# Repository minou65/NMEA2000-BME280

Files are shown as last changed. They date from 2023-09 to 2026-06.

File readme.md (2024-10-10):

# NMEA2000-BM280 environmental sensor

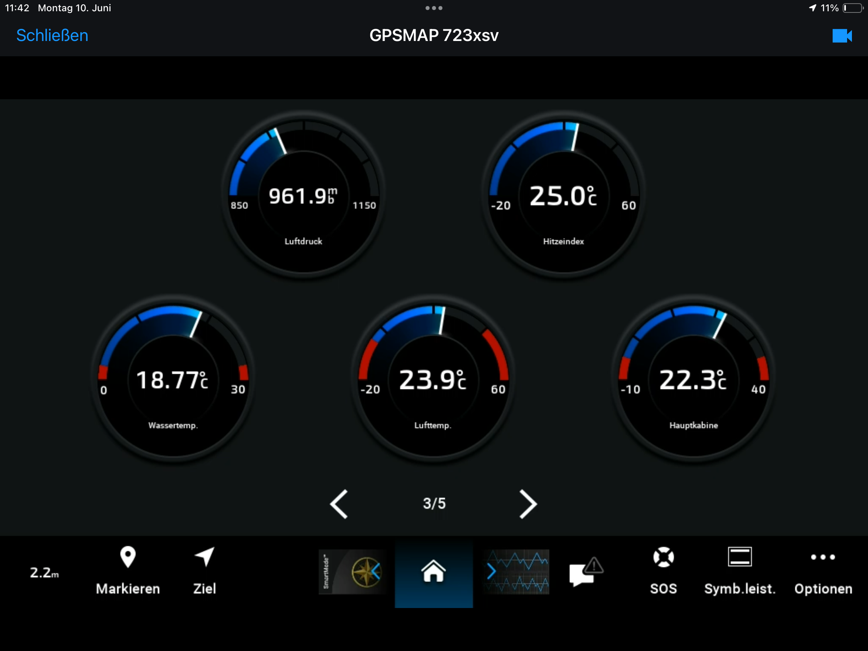
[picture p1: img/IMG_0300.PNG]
garmin


## Table of contents
- [NMEA2000-BM280 environmental sensor](#nmea2000-bm280-environmental-sensor)
  - [Table of contents](#table-of-contents)
  - [Description](#description)
  - [Schema](#schema)
  - [NMEA 2000](#nmea-2000)
  - [Librarys](#librarys)
  - [Part list](#part-list)
  - [Configuration](#configuration)
    - [System Configuration](#system-configuration)
      - [Thing name](#thing-name)
      - [AP password](#ap-password)
      - [WiFi SSID](#wifi-ssid)
      - [WiFi password](#wifi-password)
      - [AP offline mode after (minutes)](#ap-offline-mode-after-minutes)
    - [NMEA configuration](#nmea-configuration)
      - [Instance](#instance)
      - [SID](#sid)
    - [Temperatur source](#temperatur-source)
    - [Humidity source](#humidity-source)
  - [Username and password](#username-and-password)
  - [Default IP address](#default-ip-address)
  - [Firmware Update](#firmware-update)
  - [Blinking codes](#blinking-codes)
  - [Reset](#reset)

## Description
This device measures temperature, humidity, and air pressure. The dew point and perceived temperature are also calculated. The sensor used is a BM280. The values are transmitted as NMEA 2000 messages via an NMEA bus. Device configuration is done through a website, and real-time values can also be viewed on a website in addition to the NMEA bus. On the configuration page, there is a link available for convenient firmware updates.

the BME280 is a versatile environmental sensor that provides accurate measurements of temperature, humidity, and barometric pressure.
- Temperatures ranging from -40°C to +85°C with a high degree of accuracy
- relative humidity in the range of 0% to 100%
- pressure sensor data is in hPa (hectopascals) within the range of 300 hPa to 1100 hPa at temperatures from 0°C to 65°C. The absolute accuracy for pressure measurement is approximately ±1 hPa
  
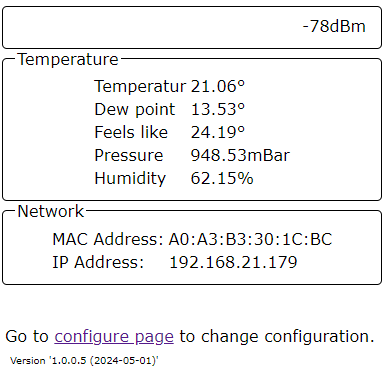
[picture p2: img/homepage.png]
homepage


In the \stl directory are two STL files. These can be used to print an appropriate housing on a 3D printer.

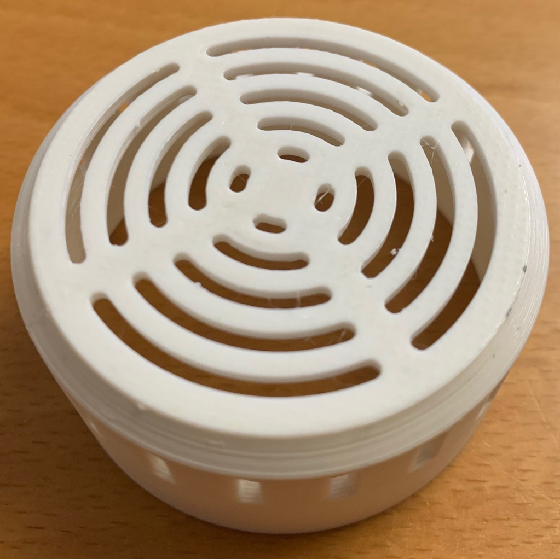
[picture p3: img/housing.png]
housing


## Schema
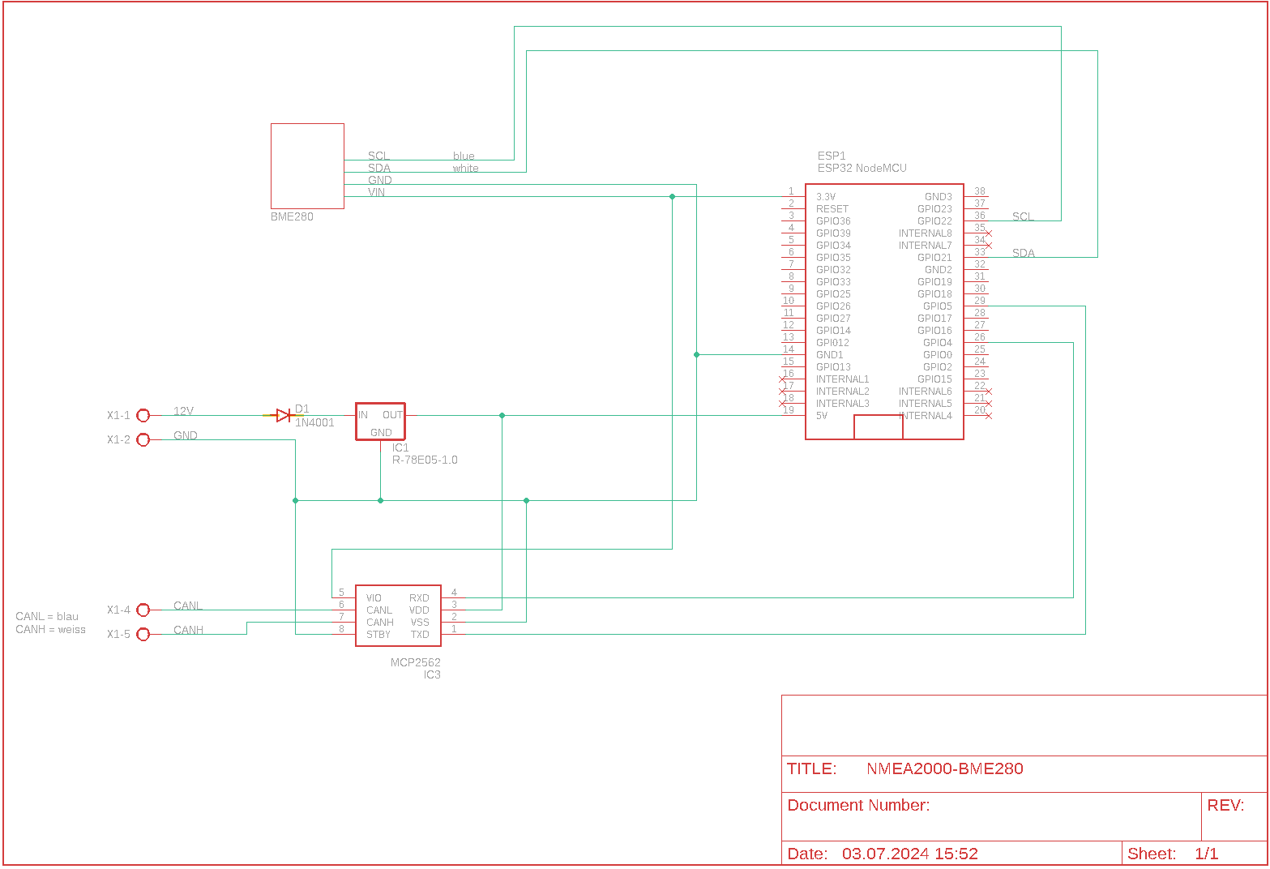
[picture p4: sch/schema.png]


## NMEA 2000
Depending on the temperature source, one of the following PNGs are sent

- 130310, // Environmental Parameters - DEPRECATED
- 130312, // Temperature - DEPRECATED
- 130316, // Temperature, Extended Range

For humidity the following PGN is sent
- 130313, // Humidity

and for pressure
- 130314, // Pressure

## Librarys
- [Adafruit BME280 Library](https://github.com/adafruit/Adafruit_BME280_Library)
- [Adafruit Unified Sensor](https://github.com/adafruit/Adafruit_Sensor)
- [NMEA2000](https://github.com/ttlappalainen/NMEA2000)
- [NMEA200_ESP32](https://github.com/ttlappalainen/NMEA2000_esp32)
- [AsyncTCP (3.2.6) __"__](https://github.com/mathieucarbou/AsyncTCP)
- [ESPAsyncWebServer (3.3.12) __*__](https://github.com/mathieucarbou/ESPAsyncWebServer)
- [Webserial (2.0.7) __*__](https://github.com/ayushsharma82/WebSerial)
- [IotWebConf](https://github.com/minou65/IotWebConf)
- [IotWebConfAsync (1.0.2) __*__](https://github.com/minou65/IotWebConfAsync)
- [IotWebRoot](https://github.com/minou65/IotWebRoot)

__*__ new version and/or new repo

## Part list
| Part | Value | Supplier |
| --- | --- | --- |
| D1 | 1N4001 | Reichelt |
| ESP1 | ESP32DEVKITV1 | [ebay](https://www.ebay.ch/itm/204191675506?var=504772734176) |
| IC1 | R-78E05-1.0 | Reichelt |
| IC3 | MCP2562 | Reichelt oder [ebay](https://www.ebay.ch/itm/364610349378) |
| X1 | AKL 057-03 | Reichelt |
| X2 | AKL 057-02 | Reichelt |
| X3 | PSS 254/4G | Reichelt |
| | BME280 | ebay |

## Configuration
After the first boot, there are some values needs to be set up.
These items are maked with __*__ (star) in the list below.

### System Configuration

#### Thing name
Please change the name of the device to a name you think describes it the most. It is advised to incorporate a location here in case you are planning to set up multiple devices in the same area. You should only use english letters, and the "_" underscore character. Thus, must not use Space, dots, etc. E.g. `main_cabin` __*__

#### AP password
This password is used, when you want to access the device later on. You must provide a password with at least 8, at most 32 characters. You are free to use any characters, further more you are encouraged to pick a password at least 12 characters long containing at least 3 character classes. __*__

#### WiFi SSID
The name of the WiFi network you want the device to connect to. __*__

#### WiFi password
The password of the network above. Note, that unsecured passwords are not supported in your protection. __*__

#### AP offline mode after (minutes)
If you don’t plan to connect the sensor to a WiFi network, you don’t need to configure the two options above. If you want to disable the WiFi after a certain time, you can use this option. Specify how long the WiFi should remain enabled after turning on the sensor. Valid values are from 0 to 30 minutes. A value of 0 means that WiFi is always enabled.

### NMEA configuration

#### Instance
This should be unique at least on one device. May be best to have it unique over all devices sending this PGN. A total of 5 instances are occupied by the device. Starting with the number set here. __*__

#### SID
Sequence identifier. In most cases you can use just 255 for SID. The sequence identifier field is used to tie different PGNs data together to same sampling or calculation time.

### Temperatur source
One of the following temperature sources can be selected
- Sea water temperature
- Outside temperature
- Inside temperature
- Engine room temperature
- Main cabin temperature
- Live well temperature
- Bait well temperature
- Refrigeration temperature
- Heating system temperature
- Freezer temperature
- Exhaust gas temperature
- Shaft seal temparature

### Humidity source
can be one of the following location
- inside
- outside
- unknown

## Username and password
Username is admin. when not connected to an AP the default password is 123456789.

## Default IP address
When in AP mode, the default IP address is 192.168.4.1

## Firmware Update
To update the firmware, navigate to the Configuration page and click on the Firmware Update link. Follow the on-screen instructions to complete the update process.

## Blinking codes
Prevoius chapters were mentioned blinking patterns, now here is a table summarize the menaning of the blink codes.

| Blinking Pattern | Meaning |
| --- | --- |
| Rapid blinking <\br>(mostly on, interrupted by short off periods) | Entered Access Point mode. This means the device creates its own WiFi network. You can connect to the device with your smartphone or WiFi capable computer. |
| Alternating on/off blinking | Trying to connect to the configured WiFi network. |
| Mostly off with occasional short flash | The device is online. |
| Mostly off with occasional long flash | The device is in offline mode |

## Reset
When CONFIG_PIN is pulled to ground on startup, the Thing will use the initial
password to buld an AP. (E.g. in case of lost password)

Reset pin is GPIO 13

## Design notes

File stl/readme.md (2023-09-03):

Source and copyright for the BME280_Sensorhouder_-_*.stl comes from here
https://www.thingiverse.com/thing:3490042

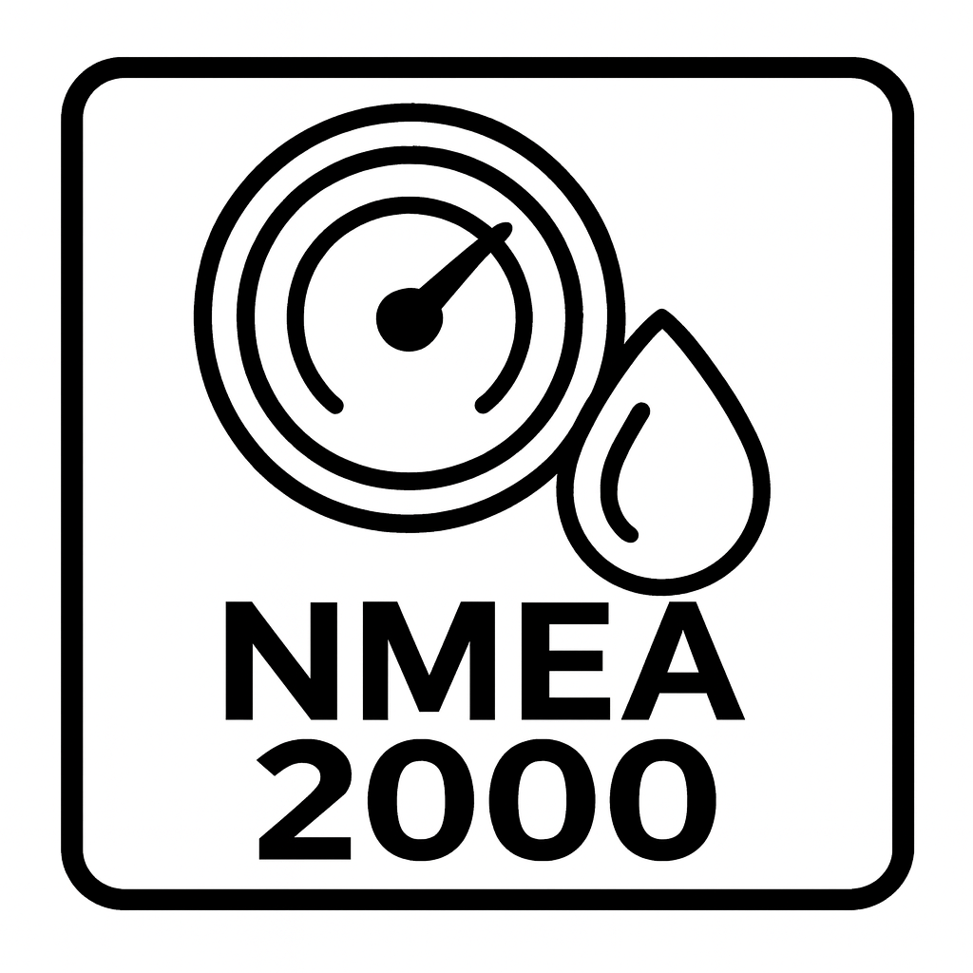
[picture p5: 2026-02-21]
img/nmea2000-umwelt.png

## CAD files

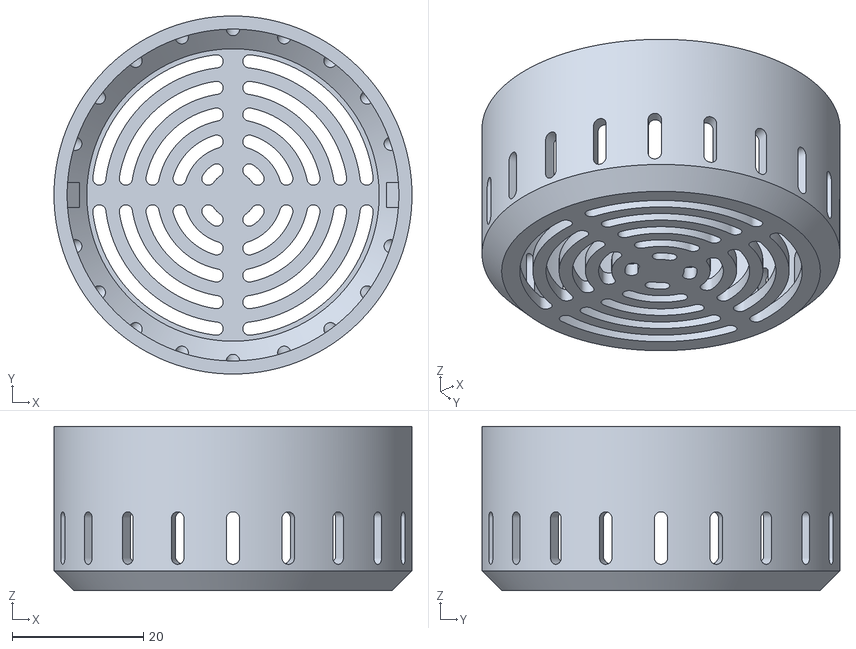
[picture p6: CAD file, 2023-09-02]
stl/BME280_Sensorhouder_-_Top.stl
54.5 x 54.5 x 25.0

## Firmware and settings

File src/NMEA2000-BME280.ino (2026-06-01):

// #define DEBUG_NMEA_MSG // Uncomment to see, what device will send to bus. Use e.g. OpenSkipper or Actisense NMEA Reader  
// #define DEBUG_NMEA_MSG_ASCII // If you want to use simple ascii monitor like Arduino Serial Monitor, uncomment this line
// #define DEBUG_NMEA_Actisense // Uncomment this, so you can test code without CAN bus chips on Arduino Mega

#define DEBUG_MSG

// use the following Pins

#define ESP32_CAN_TX_PIN GPIO_NUM_5  // Set CAN TX port to D5 
#define ESP32_CAN_RX_PIN GPIO_NUM_4  // Set CAN RX port to D4

#include <Adafruit_Sensor.h>
#include <Adafruit_BME280.h>
#include <N2kMessages.h>
#include <NMEA2000_CAN.h>
#include <cmath>
#include <esp_task_wdt.h>
#include <esp_mac.h>
#include <RebootManager.h>

#include "common.h"
#include "webhandling.h"
#include "version.h"
#include "neotimer.h"

bool debugMode = false;
String gStatusSensor;
char Version[] = VERSION_STR; // Manufacturer's Software version code

uint8_t gN2KSource[] = { 22, 23, 24 };
uint8_t gN2KInstance = 1;
uint8_t gN2KSID = 1;
tN2kTempSource gTempSource = N2kts_MainCabinTemperature;
tN2kHumiditySource gHumiditySource = N2khs_Undef;

tN2kSyncScheduler TemperatureScheduler(false, 2000, 500);
tN2kSyncScheduler HumidityScheduler(false, 500, 510);
tN2kSyncScheduler PressureScheduler(false, 500, 520);
tN2kSyncScheduler DewPointScheduler(false, 500, 530);
tN2kSyncScheduler HeatIndexScheduler(false, 500, 540);

// Define a function to calculate the dew point
double dewPoint(double temp_celsius, double humidity) {
    const double a = 17.27;
    const double b = 237.7;
    double alpha = ((a * temp_celsius) / (b + temp_celsius)) + log(humidity / 100.0);
    return (b * alpha) / (a - alpha);

}

// This function takes the temperature in Celsius and the relative humidity in percentage
// and returns the heat index temperature in Celsius
double heatIndexCelsius(double temp_celsius, double humidity) {
    // These are the constants used in the formula
    const double c1 = -42.379;
    const double c2 = 2.04901523;
    const double c3 = 10.14333127;
    const double c4 = -0.22475541;
    const double c5 = -0.00683783;
    const double c6 = -0.05481717;
    const double c7 = 0.00122874;
    const double c8 = 0.00085282;
    const double c9 = -0.00000199;

    // Convert the temperature from Celsius to Fahrenheit
    double temp_fahrenheit = temp_celsius * 9.0 / 5.0 + 32;

    // Calculate the heat index in Fahrenheit
    double heat_fahrenheit = c1 + c2 * temp_fahrenheit + c3 * humidity + c4 * temp_fahrenheit * humidity + c5 * temp_fahrenheit * temp_fahrenheit + c6 * humidity * humidity + c7 * temp_fahrenheit * temp_fahrenheit * humidity + c8 * temp_fahrenheit * humidity * humidity + c9 * temp_fahrenheit * temp_fahrenheit * humidity * humidity;

    // Convert the heat index from Fahrenheit to Celsius
    double heat_celsius = (heat_fahrenheit - 32) * 5.0 / 9.0;

    // Return the result
    return heat_celsius;
}


double gTemperature = 0;
double gHumidity = 0;
double gPressure = 0;
double gdewPoint = 0;
double gheatIndex = 0;

// Task handle (Core 0 on ESP32)
TaskHandle_t TaskHandle;

Adafruit_BME280 bme;

// List here messages your device will transmit.
const unsigned long TemperaturTransmitMessages[] PROGMEM = {
    130312L, // Temperature
    130316L,
    0
};

const unsigned long HumidityTransmitMessages[] PROGMEM = {
    130313L, // Humidity
    0
};

const unsigned long PressureTransmitMessages[] PROGMEM = {
    130314L, // Pressure
    0
};

void OnN2kOpen() {
    // Start schedulers now.
    TemperatureScheduler.UpdateNextTime();
    HumidityScheduler.UpdateNextTime();
    PressureScheduler.UpdateNextTime();
    DewPointScheduler.UpdateNextTime();
    HeatIndexScheduler.UpdateNextTime();
}

void CheckN2kSourceAddressChange() {
    uint8_t SourceAddress = NMEA2000.GetN2kSource();

    if (NMEA2000.GetN2kSource(DeviceTemperature) != gN2KSource[DeviceTemperature]) {
        gN2KSource[DeviceTemperature] = NMEA2000.GetN2kSource(DeviceTemperature);
        gSaveParams = true;
    }

    if (NMEA2000.GetN2kSource(DevicePressure) != gN2KSource[DevicePressure]) {
        gN2KSource[DevicePressure] = NMEA2000.GetN2kSource(DevicePressure);
        gSaveParams = true;
    }

    if (NMEA2000.GetN2kSource(DeviceHumidity) != gN2KSource[DeviceHumidity]) {
        gN2KSource[DeviceHumidity] = NMEA2000.GetN2kSource(DeviceHumidity);
        gSaveParams = true;
    }
}

void setup() {
    uint8_t chipid[6];
    uint64_t DeviceId1 = 0;
    uint64_t DeviceId2 = 0;
    uint64_t DeviceId3 = 0;
    int i = 0;

    // Generate unique numbers from chip id
    esp_efuse_mac_get_default(chipid);

    for (int i = 0; i < 6; i++) {
        DeviceId1 += (chipid[i] << (7 * i));
        DeviceId2 += (chipid[i] << (8 * i)); // 8*i statt 7*i
        DeviceId3 += (chipid[i] << (9 * i)); // 9*i statt 7*i oder 8*i
    }

    Serial.begin(115200);
    while (!Serial) {
        delay(1);
    }

    Serial.printf("Firmware version:%s\n", VERSION);

    RebootManager::begin();
    Serial.printf("Reboot count: %d\n", RebootManager::getRebootCount());
    Serial.printf("Last reboot reason: %s\n", RebootManager::getLastRebootReasonText().c_str());

    // init wifi
    wifiInit();

    gStatusSensor = "OK";
    if (!bme.begin(BME280_ADDRESS_ALTERNATE)) {
        gStatusSensor = "NOK";
		DEBUG_PRINTLN(F("Could not find a valid BME280 sensor, check wiring!"));
    }
	

    xTaskCreatePinnedToCore(
        loop2, /* Function to implement the task */
        "TaskHandle", /* Name of the task */
        10000,  /* Stack size in words */
        NULL,  /* Task input parameter */
        0,  /* Priority of the task */
        &TaskHandle,  /* Task handle. */
        0 /* Core where the task should run */
    );

    // Enable multi device support for 3 devices
    NMEA2000.SetDeviceCount(3); 

    NMEA2000.SetOnOpen(OnN2kOpen);

    // Reserve enough buffer for sending all messages. This does not work on small memory devices like Uno or Mega
    NMEA2000.SetN2kCANMsgBufSize(8);
    NMEA2000.SetN2kCANReceiveFrameBufSize(150);
    NMEA2000.SetN2kCANSendFrameBufSize(150);

    // Set Product information
    NMEA2000.SetProductInformation(
        "101", // Manufacturer's Model serial code
        101, // Manufacturer's product code
        "BME280-TemperaturMonitor",  // Manufacturer's Model ID
        Version,  // Manufacturer's Software version code
        Version, // Manufacturer's Model version
        1, // load equivalency
        0xffff, // NMEA 2000 version - use default
        0xff, // Sertification level - use default
        DeviceTemperature
    );

    NMEA2000.SetProductInformation(
        "102", // Manufacturer's Model serial code
        102, // Manufacturer's product code
        "BME280-Pressure",  // Manufacturer's Model ID
        Version,  // Manufacturer's Software version code
        Version, // Manufacturer's Model version
        1, // load equivalency
        0xffff, // NMEA 2000 version - use default
        0xff, // Sertification level - use default
        DevicePressure
    );

    NMEA2000.SetProductInformation(
        "103", // Manufacturer's Model serial code
        103, // Manufacturer's product code
        "BME280-HumidityMonitor",  // Manufacturer's Model ID
        Version,  // Manufacturer's Software version code
        Version, // Manufacturer's Model version
        1, // load equivalency
        0xffff, // NMEA 2000 version - use default
        0xff, // Sertification level - use default
        DeviceHumidity
    );

    // Set device information
    NMEA2000.SetDeviceInformation(
        DeviceId1, // Unique number. Use e.g. Serial number.
        130, // Device function=Devices that measure/report temperature
        75, // Device class=Sensor Communication Interface.
        2046, // Just choosen free from code list on 
        4,  // Marine
        DeviceTemperature
    );

    NMEA2000.SetDeviceInformation(
        DeviceId2, // Unique number. Use e.g. Serial number.
        140, // Device function=Devices that measure/report pressure.
        75, // Device class=Sensor Communication Interface.
        2046, // Just choosen free from code list on 
        4,  // Marine
        DevicePressure
    );

    NMEA2000.SetDeviceInformation(
        DeviceId3, // Unique number. Use e.g. Serial number.
        170, // Device function=Devices that measure/report humidity.
        75, // Device class=Sensor Communication Interface.
        2046, // Just choosen free from code list on 
        4,  // Marine
        DeviceHumidity
    );

    // Disable all msg forwarding to USB (=Serial)
    NMEA2000.EnableForward(false); 

    // If you also want to see all traffic on the bus use N2km_ListenAndNode instead of N2km_NodeOnly below
    NMEA2000.SetMode(tNMEA2000::N2km_NodeOnly);

    NMEA2000.SetN2kSource(gN2KSource[DeviceTemperature], DeviceTemperature);
    NMEA2000.SetN2kSource(gN2KSource[DevicePressure], DevicePressure);
    NMEA2000.SetN2kSource(gN2KSource[DeviceHumidity], DeviceHumidity);


    // Here we tell library, which PGNs we transmit
    NMEA2000.ExtendTransmitMessages(TemperaturTransmitMessages);
    NMEA2000.ExtendTransmitMessages(PressureTransmitMessages);
    NMEA2000.ExtendTransmitMessages(HumidityTransmitMessages);
        
    NMEA2000.Open();

    esp_task_wdt_add(NULL); //add current thread to WDT watch
}

void SendN2kTemperature(uint8_t instance_) {
    tN2kMsg N2kMsg;
    double Temperature = 0.00;

    if (TemperatureScheduler.IsTime()) {
        TemperatureScheduler.UpdateNextTime();

		if (gStatusSensor != "NOK") {
            Temperature = bme.readTemperature();
		}
        
        SetN2kPGN130312(N2kMsg, gN2KSID, instance_, gTempSource, CToKelvin(Temperature), N2kDoubleNA);
        NMEA2000.SendMsg(N2kMsg, DeviceTemperature);

        SetN2kPGN130316(N2kMsg, gN2KSID, instance_, gTempSource, CToKelvin(Temperature), N2kDoubleNA);
        NMEA2000.SendMsg(N2kMsg, DeviceTemperature);

        gTemperature = Temperature;
    }
}

void SendN2kHumidity(uint8_t instance_) {
    tN2kMsg N2kMsg;
    double Humidity = 0.00;

    if (HumidityScheduler.IsTime()) {
        HumidityScheduler.UpdateNextTime();

        if (gStatusSensor != "NOK") {
            Humidity = bme.readHumidity();
        }
        SetN2kPGN130313(N2kMsg, gN2KSID, instance_, gHumiditySource, Humidity, N2kDoubleNA);
        NMEA2000.SendMsg(N2kMsg, DeviceHumidity);
        gHumidity = Humidity;
    }
}

void SendN2kPressure(uint8_t instance_) {
    tN2kMsg N2kMsg;
    double Pressure = 0.00;

    if (PressureScheduler.IsTime()) {
        PressureScheduler.UpdateNextTime();
        if (gStatusSensor != "NOK") {
            Pressure = bme.readPressure() / 100.0f;  // Read and convert to mBar 
        }
        else {
           WebSerial.println(F("Could not find a valid BME280 sensor, check wiring!"));
        }
        SetN2kPGN130314(N2kMsg, gN2KSID, instance_, N2kps_Atmospheric, mBarToPascal(Pressure));
        NMEA2000.SendMsg(N2kMsg, DevicePressure);
        gPressure = Pressure;
    }
}

void SendN2KHeatIndexTemperature(double Temperatur_, double Humidity_, uint8_t instance_) {
    tN2kMsg N2kMsg;
	double _heatIndex = 0.00;

    if (HeatIndexScheduler.IsTime()) {
        HeatIndexScheduler.UpdateNextTime();

        if (gStatusSensor != "NOK") {
			_heatIndex = heatIndexCelsius(Temperatur_, Humidity_);
		}

        SetN2kPGN130312(N2kMsg, gN2KSID, instance_, N2kts_HeatIndexTemperature, CToKelvin(_heatIndex), N2kDoubleNA);
        NMEA2000.SendMsg(N2kMsg, DeviceTemperature);

        SetN2kPGN130316(N2kMsg, gN2KSID, instance_, N2kts_HeatIndexTemperature, CToKelvin(_heatIndex), N2kDoubleNA);
        NMEA2000.SendMsg(N2kMsg, DeviceTemperature);

        gheatIndex = _heatIndex;
    }
}

void SendN2KDewPointTemperature(double Temperatur_, double Humidity_, uint8_t instance_) {
    tN2kMsg N2kMsg;
	double _dewPoint = 0.00;

    if (DewPointScheduler.IsTime()) {
        DewPointScheduler.UpdateNextTime();
		if (gStatusSensor != "NOK") {
			_dewPoint = dewPoint(Temperatur_, Humidity_);
		}

        SetN2kPGN130312(N2kMsg, gN2KSID, instance_, N2kts_DewPointTemperature, CToKelvin(_dewPoint), N2kDoubleNA);
        NMEA2000.SendMsg(N2kMsg, DeviceTemperature);

        SetN2kPGN130316(N2kMsg, gN2KSID, instance_, N2kts_DewPointTemperature, CToKelvin(_dewPoint), N2kDoubleNA);
        NMEA2000.SendMsg(N2kMsg, DeviceTemperature);

        gdewPoint = _dewPoint;
    }
}

void loop() {
    SendN2kTemperature(gN2KInstance);
    SendN2kHumidity(gN2KInstance + 1);
    SendN2kPressure(gN2KInstance + 2);

    SendN2KHeatIndexTemperature(gTemperature, gHumidity, gN2KInstance + 3);
    SendN2KDewPointTemperature(gTemperature, gHumidity, gN2KInstance + 4);

    NMEA2000.ParseMessages();
    CheckN2kSourceAddressChange();

    gParamsChanged = false;

    // Dummy to empty input buffer to avoid board to stuck with e.g. NMEA Reader
    if (Serial.available()) {
        Serial.read();
    }

    esp_task_wdt_reset();
}

void loop2(void* parameter) {
    esp_task_wdt_add(NULL); //add current thread to WDT watch (Core 0)
    for (;;) {   // Endless loop
        wifiLoop();

        esp_task_wdt_reset();

        vTaskDelay(100);
    }
}

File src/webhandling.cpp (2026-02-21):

// #define DEBUG_WIFI(m) SERIAL_DBG.print(m)

#include <Arduino.h>
#include <ArduinoOTA.h>
#if defined(ESP32)
#include <WiFi.h>
// #include <esp_wifi.h>
#elif defined(ESP8266)
#include <ESP8266WiFi.h>
#else
#error "Unsupported platform"
#endif

#include "common.h"
#include "webhandling.h"
#include "favicon.h"
#include "neotimer.h"

#include <DNSServer.h>
#include <IotWebConfAsyncUpdateServer.h>
#include <IotWebRoot.h>


// -- Configuration specific key. The value should be modified if config structure was changed.
#define CONFIG_VERSION "A2"

// -- When CONFIG_PIN is pulled to ground on startup, the Thing will use the initial
//      password to buld an AP. (E.g. in case of lost password)
#define CONFIG_PIN  GPIO_NUM_13

// -- Status indicator pin.
//      First it will light up (kept LOW), on Wifi connection it will blink,
//      when connected to the Wifi it will turn off (kept HIGH).
#define STATUS_PIN LED_BUILTIN

#if ESP32 
#define ON_LEVEL HIGH
#else
#define ON_LEVEL LOW
#endif

// -- Initial name of the Thing. Used e.g. as SSID of the own Access Point.
const char thingName[] = "NMEA2000-BME280";

// -- Method declarations.
void handleData(AsyncWebServerRequest* request);
void handleRoot(AsyncWebServerRequest* request);
void convertParams();

// -- Callback methods.
void configSaved();
void wifiConnected();

bool gParamsChanged = true;
bool gSaveParams = false;
uint8_t APModeOfflineTime = 0;

DNSServer dnsServer;
AsyncWebServer server(80);
AsyncWebServerWrapper asyncWebServerWrapper(&server);
AsyncUpdateServer AsyncUpdater;
Neotimer APModeTimer = Neotimer();

AsyncIotWebConf iotWebConf(thingName, &dnsServer, &asyncWebServerWrapper, wifiInitialApPassword, CONFIG_VERSION);

NMEAConfig Config = NMEAConfig();

iotwebconf::ParameterGroup SourcesGroup = iotwebconf::ParameterGroup("SourcesGroup", "Source");

char TempSourceValue[STRING_LEN];
iotwebconf::SelectParameter TempSource = iotwebconf::SelectParameter("Temperature",
    "TempSource", 
    TempSourceValue,
    STRING_LEN, 
    (char*)TempSourceValues,
    (char*)TempSourceNames,
    sizeof(TempSourceValues) / STRING_LEN,
    STRING_LEN,
    "4" // Main cabin temperature
);

char HumiditySourceValue[STRING_LEN];
iotwebconf::SelectParameter HumiditySource = iotwebconf::SelectParameter("Humidity",
    "HumiditySource",
    HumiditySourceValue,
    STRING_LEN,
    (char*)HumiditySourceValues,
    (char*)HumiditySourceNames,
    sizeof(HumiditySourceValues) / STRING_LEN,
    STRING_LEN,
    "2" // undefined
);

class CustomHtmlFormatProvider : public iotwebconf::HtmlFormatProvider {
protected:
    virtual String getFormEnd() {
        String _s = HtmlFormatProvider::getFormEnd();
        _s += F("</br>Return to <a href='/'>home page</a>.");
        return _s;
    }
};
CustomHtmlFormatProvider customHtmlFormatProvider;

char APModeOfflineValue[STRING_LEN];
iotwebconf::NumberParameter APModeOfflineParam = iotwebconf::NumberParameter("AP offline mode after (minutes)", "APModeOffline", APModeOfflineValue, NUMBER_LEN, "0", "0..30", "min='0' max='30', step='1'");


void wifiInit() {
    Serial.begin(115200);
    Serial.println();
    Serial.println("starting up...");


    iotWebConf.setStatusPin(STATUS_PIN, ON_LEVEL);
    iotWebConf.setConfigPin(CONFIG_PIN);
    iotWebConf.setHtmlFormatProvider(&customHtmlFormatProvider);

    SourcesGroup.addItem(&TempSource);
    SourcesGroup.addItem(&HumiditySource);

    iotWebConf.addParameterGroup(&Config);
    iotWebConf.addParameterGroup(&SourcesGroup);

    iotWebConf.addSystemParameter(&APModeOfflineParam);
    
    iotWebConf.setupUpdateServer(
        [](const char* updatePath) { AsyncUpdater.setup(&server, updatePath); },
        [](const char* userName, char* password) { AsyncUpdater.updateCredentials(userName, password); });

    iotWebConf.setConfigSavedCallback(&configSaved);
    iotWebConf.setWifiConnectionCallback(&wifiConnected);

    iotWebConf.getApTimeoutParameter()->visible = true;

    // -- Initializing the configuration.
    iotWebConf.init();

    convertParams();

    // -- Set up required URL handlers on the web server.
    server.on("/", HTTP_GET, [](AsyncWebServerRequest* request) { handleRoot(request); });

    server.on("/config", HTTP_ANY, [](AsyncWebServerRequest* request) {
        AsyncWebRequestWrapper asyncWebRequestWrapper(request);
        iotWebConf.handleConfig(&asyncWebRequestWrapper);
        }
    );

    server.on("/favicon.ico", HTTP_GET, [](AsyncWebServerRequest* request) {
        AsyncWebServerResponse* response = request->beginResponse_P(200, "image/x-icon", favicon_ico, sizeof(favicon_ico));
        request->send(response);
        }
    );

    server.on("/apple-touch-icon.png", HTTP_GET, [](AsyncWebServerRequest* request) {
        AsyncWebServerResponse* response = request->beginResponse_P(200, "image/png", favicon_ico, sizeof(favicon_ico));
        request->send(response);
        }
    );

    server.on("/data", HTTP_GET, [](AsyncWebServerRequest* request) { handleData(request); });
    server.onNotFound([](AsyncWebServerRequest* request) {
        AsyncWebRequestWrapper asyncWebRequestWrapper(request);
        iotWebConf.handleNotFound(&asyncWebRequestWrapper);
        }
    );

	WebSerial.begin(&server, "/webserial");

    if (APModeOfflineTime > 0) {
        APModeTimer.start(APModeOfflineTime * 60 * 1000);
    }

    Serial.println("Ready.");
}

void wifiLoop() {
    // -- doLoop should be called as frequently as possible.
    iotWebConf.doLoop();
    ArduinoOTA.handle();

    if (gSaveParams) {
        Serial.println(F("Parameters are changed,save them"));

        Config.SetSource(gN2KSource[DeviceTemperature]);
        Config.SetSourceHumidity(gN2KSource[DeviceHumidity]);
        Config.SetSourcePressure(gN2KSource[DevicePressure]);

        iotWebConf.saveConfig();
        gSaveParams = false;
    }

    if (APModeTimer.done()) {
        Serial.println(F("AP mode offline time reached"));
        iotWebConf.goOffLine();
        APModeTimer.stop();
    }

    if (AsyncUpdater.isFinished()) {
        Serial.println(F("Firmware update finished"));
        delay(1000);
        ESP.restart();
    }
}

void wifiConnected() {
    ArduinoOTA.begin();
}

void handleData(AsyncWebServerRequest* request) {
	String json_ = "{";
	json_ += "\"rssi\":" + String(WiFi.RSSI()) + ",";
	json_ += "\"Temperature\":" + String(gTemperature, 2) + ",";
	json_ += "\"DewPoint\":" + String(gdewPoint, 2) + ",";
	json_ += "\"HeatIndex\":" + String(gheatIndex, 2) + ",";
	json_ += "\"Pressure\":" + String(gPressure, 2) + ",";
	json_ += "\"Humidity\":" + String(gHumidity, 2);
	json_ += "}";
	request->send(200, "application/json", json_);
}
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

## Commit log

2024-01-02 schema added
    [NMEA2000-BME280.sch]
2024-01-02 temperature sources changed
2024-01-02 heatindex, dewpoint and SID added
2024-01-02 dewpoint and heatindex added
2024-01-05 device function changed
2024-02-04 generate for each device his uid
2024-02-12 instance per sensortype
2024-05-01 reset pin changed
2024-05-01 bug in main website fixed
    [webhandling.cpp]
2024-05-13 use ArduinoJSON for creating JSON
2024-05-13 fixed a bug in handleRoot
    [webhandling.cpp]
2024-05-13 Status for I2C bus added
2024-06-13 links shortened to subpages
    [webhandling.cpp]
2024-07-03 added some missing values
    [NMEA2000-BME280.sch]
2024-07-26 task watchdog timer added
2024-10-07 Updated to ESPAsyncWebServer version 3.3.12 and removed dependency on ArduinoJson.
2025-04-14 Refactor Watchdog Timer configuration and initialization in NMEA2000-BME280
2025-05-30 Set ArduinoOTA hostname to the Thing's name
2026-06-01 Refactor: integrate RebootManager and remove Watchdog Timer configuration
    [NMEA2000-BME280.ino]
